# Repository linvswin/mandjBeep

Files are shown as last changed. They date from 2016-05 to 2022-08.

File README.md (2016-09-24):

#### Working in progress !!!
# mandjBeep
## Cosa &egrave;? 
Centralina di allarme modulare pilotata da un atmega1284. 
### Storia
Il progetto &egrave; nato dall'esigenza di in stallare un sistema di allarme in casa. La prima bozza prevedeva l'uso di un atmega328, ma poi con crescere delle
funzionalit&agrave;, sono stato costretto a trovare un microcontrollore con un po di memoria in pi&ugrave;. La scelta &egrave; ricaduta su un atmega1284. Di seguito un comparazione 
tra i microcontrollori pi&ugrave; diffusi (Arduino like) 

<table>
	<tr><th>Feature</th><th>328P</th><th>1284P</th><th>2560P</th></tr>
	<tr><td>Price</td><td>$2.99</td><td>$4.66</td><td>$11.28</td></tr>
	<tr><td>RAM</td><td>2k</td><td>16k</td><td>8k</td></tr>
	<tr><td>Flash</td><td>32k</td><td>128k</td><td>256k</td></tr>
	<tr><td>EEPROM</td><td>1k</td><td>4k</td><td>4k</td></tr>
	<tr><td>UART</td><td>1</td><td>2</td><td>4</td></tr>
	<tr><td>IO Pins</td><td>23</td><td>32</td><td>86</td></tr>
	<tr><td>Interrupts</td><td>2</td><td>3</td><td>8</td></tr>
	<tr><td>Analog Inputs</td><td>6</td><td>8</td><td>16</td></tr>
</table>

### Caratteristiche:

* RTC: modulo DS3231 per la gestione del tempo
* LCD 20x4 per impostazioni/visualizzazione stato, etc (collegato ad un PCF8574 che lo rende I2C)
* tastierino 4x4 (tastierino a membrana classico x arduino collegato ad un PCF8574 che lo rende I2C)
* 2 zone (da implementare)
* avviso tramite modulo GSM (al momento solo tramite sms)
* relay per attivizione sirena.
* batteria tampone al piombo 12v 7A

## Librerie usate

* [Keypad_I2C](https://github.com/joeyoung/arduino_keypads/tree/master/Keypad_I2C): libreria per la gestione del tastierino I2C.
* [LCDMenuLib](https://github.com/Jomelo/LCDMenuLib): libreria per la gestione del menu.
* [secTimer](https://github.com/leomil72/secTimer): Simple seconds counter for Arduino boards and Atmel microcontrollers.
The library can count from 0 to (2^32)-1 seconds. This is a really HUGE
interval of time since (2^32)-1 seconds are about 136 years! So your
device will cease to function before the library will overflow!
* MandjTimer: modificato la libreria [Timer](http://playground.arduino.cc/Code/Timer) per utilizzare secTimer al posto di millis().
* [Password](http://playground.arduino.cc/Code/Password): libreria per la gestione del codice di accesso.
* [PCF8574](https://github.com/RobTillaart/Arduino/tree/master/libraries/PCF8574): libreria per la gestione dei moduli sensore, gestione dell'integrato PCF8574.
* [Rtc_by_Makuna](https://github.com/Makuna/Rtc): liberia per la gestione del modulo DS3231 pe la gestione del tempo.
* [TimerOneThree](https://github.com/heliosoph/TimerOneThree):  The arduino TimerOne library adapted for ATmega1284P and extended for timer3.
* [GSM Shield](http://www.gsmlib.org): a library developed for Arduino's shields that support SIM900/SIM908.
* [Keypad](http://playground.arduino.cc/Code/Keypad): a library for using <em>matrix</em> style keypads with the Arduino. As of version 3.0 it now supports mulitple keypresses.
* [NewLiquidCrystal](https://bitbucket.org/fmalpartida/new-liquidcrystal/wiki/Home): the <em>LCD Library</em> for <strong>Arduino</strong> and <strong>Chipkit</strong>. It is a derivate of the original LiquidCrystal Library as sourced in the Arduino SDK. It has been developed to be compatible with the current LiquidCrystal library, its performance is almost 5 times faster and fully extendable if need be.
* [SoftwareSerial](https://www.arduino.cc/en/Reference/SoftwareSerial): library has been developed to allow serial communication on other digital pins of the Arduino, using software to replicate the functionality.
* [Wire](https://www.arduino.cc/en/Reference/Wire): library allows you to communicate with <span class="wikiword">I2C</span> / TWI devices.
 
##  Author

* M&J 
* Sito: [siatienfalla](http://siatienfalla.altervista.org/)
* Data inizio: 09/02/2016
* Versione: 1.0
 
## Licence: GPL ver. 3

## Immagini
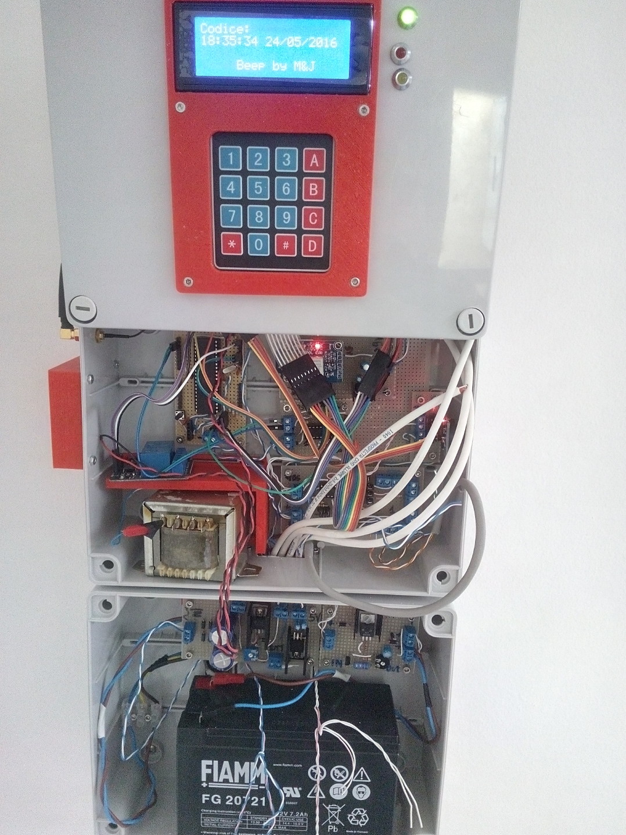
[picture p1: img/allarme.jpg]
Allarme


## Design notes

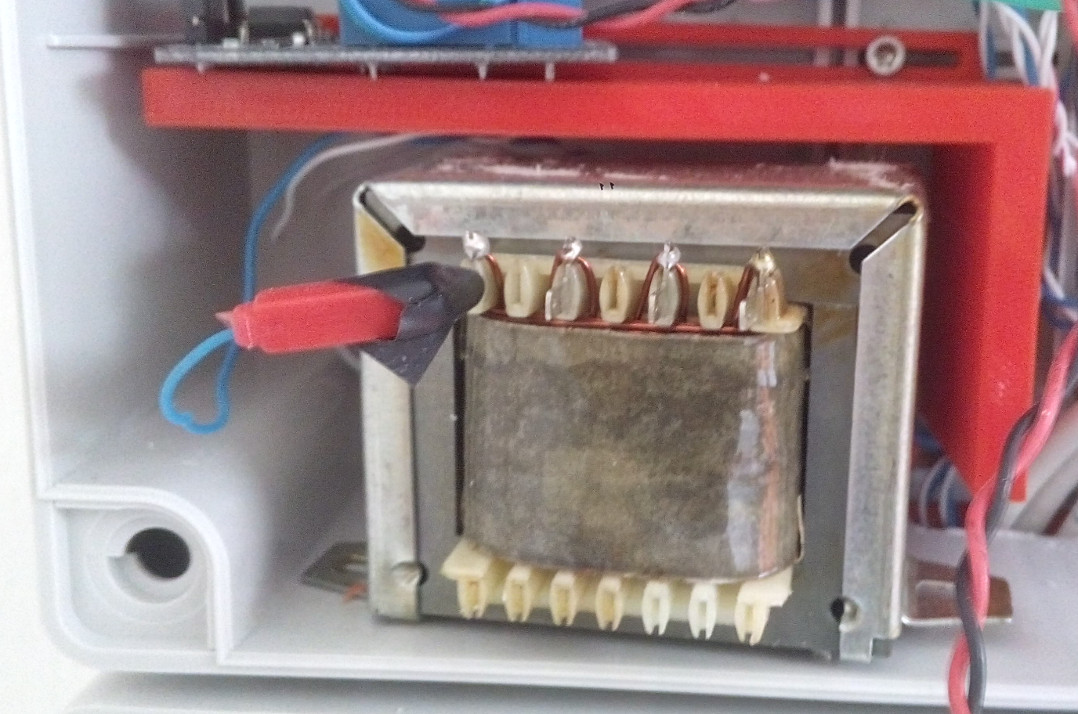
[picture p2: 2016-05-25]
img/moduloTrasformatore.jpg

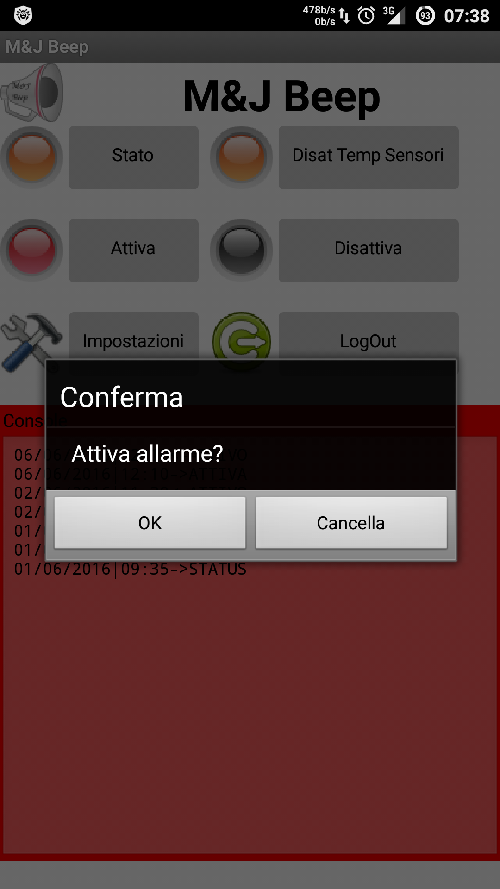
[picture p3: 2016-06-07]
android/img/Screenshot_2016-06-06-07-38-11.png

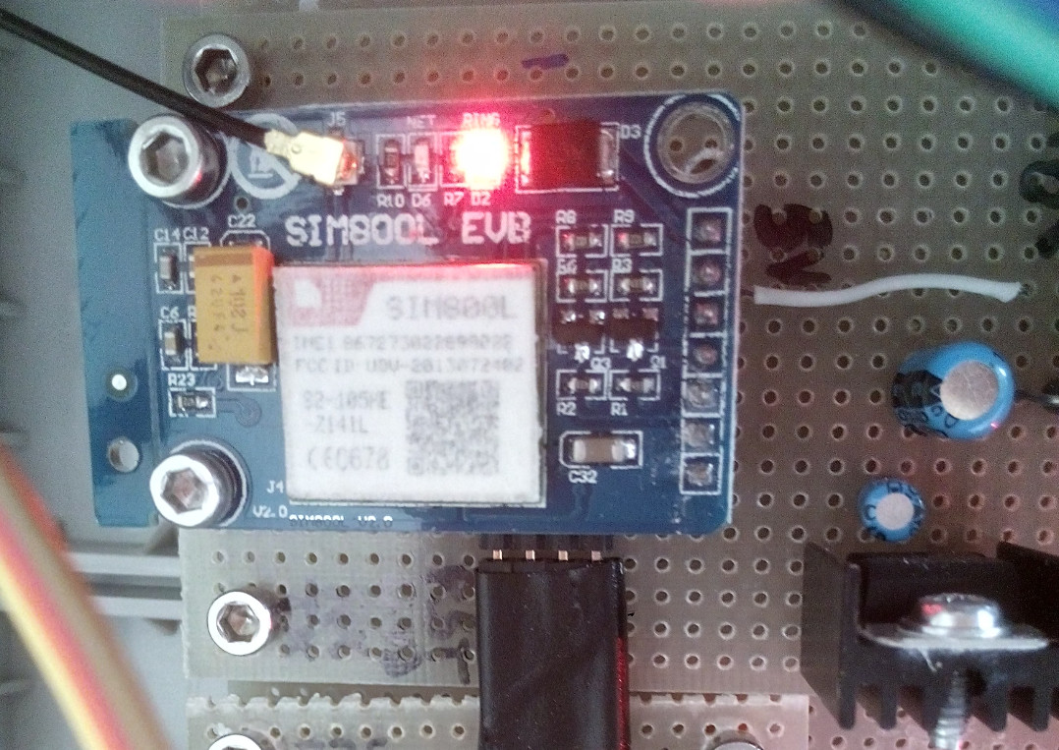
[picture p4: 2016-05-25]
img/moduloGSM.jpg

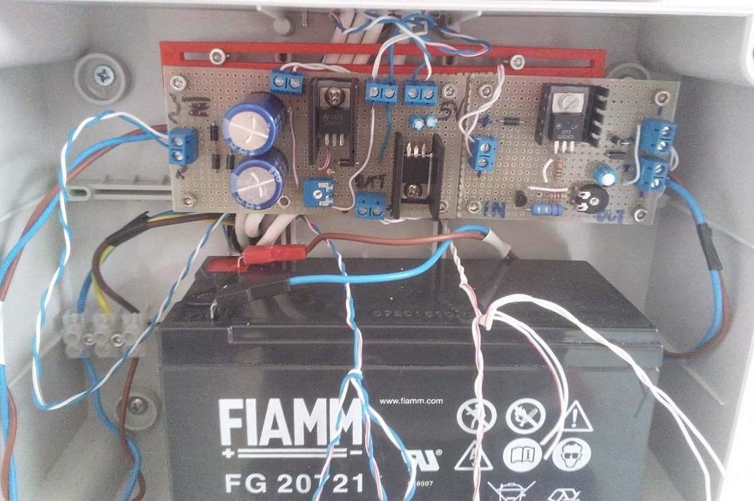
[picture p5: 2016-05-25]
img/moduloAlimentazione.jpg

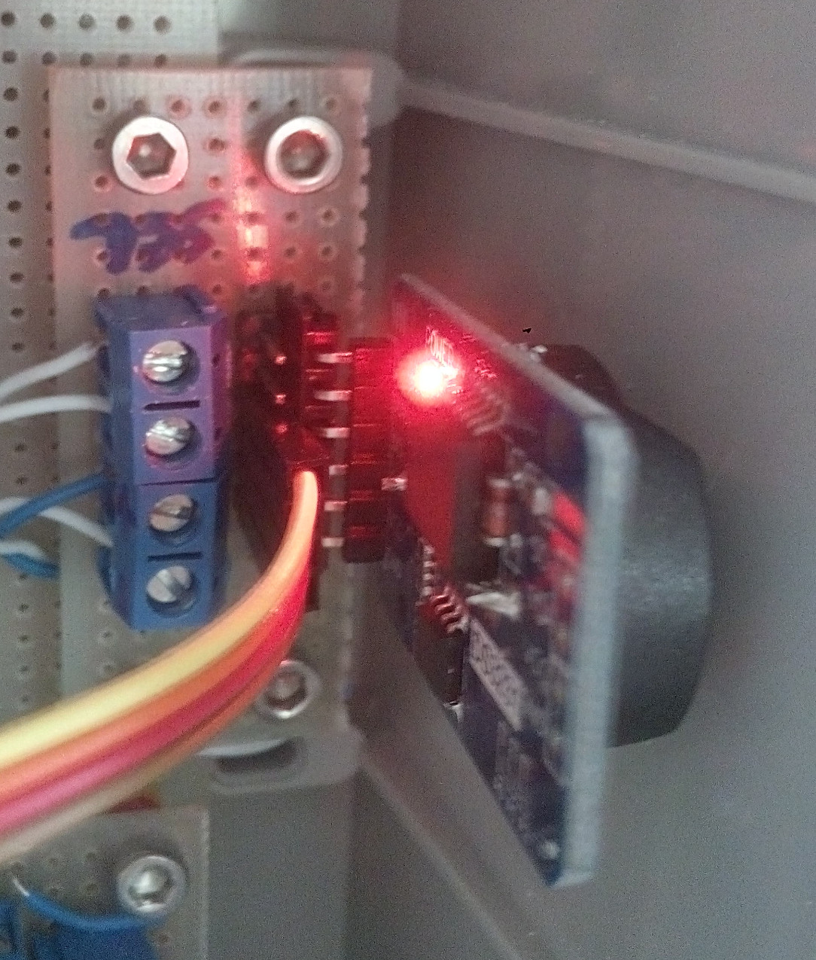
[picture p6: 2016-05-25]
img/moduloTempoLCD.jpg

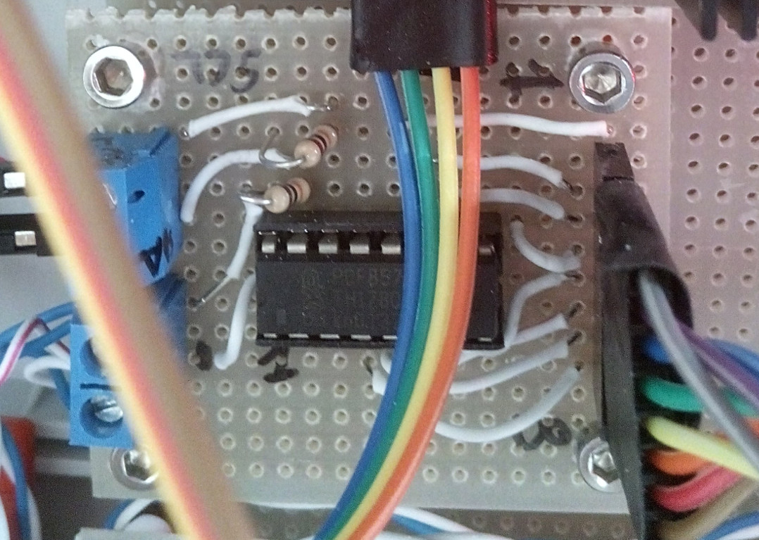
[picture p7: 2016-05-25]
img/moduloKeyPad.jpg

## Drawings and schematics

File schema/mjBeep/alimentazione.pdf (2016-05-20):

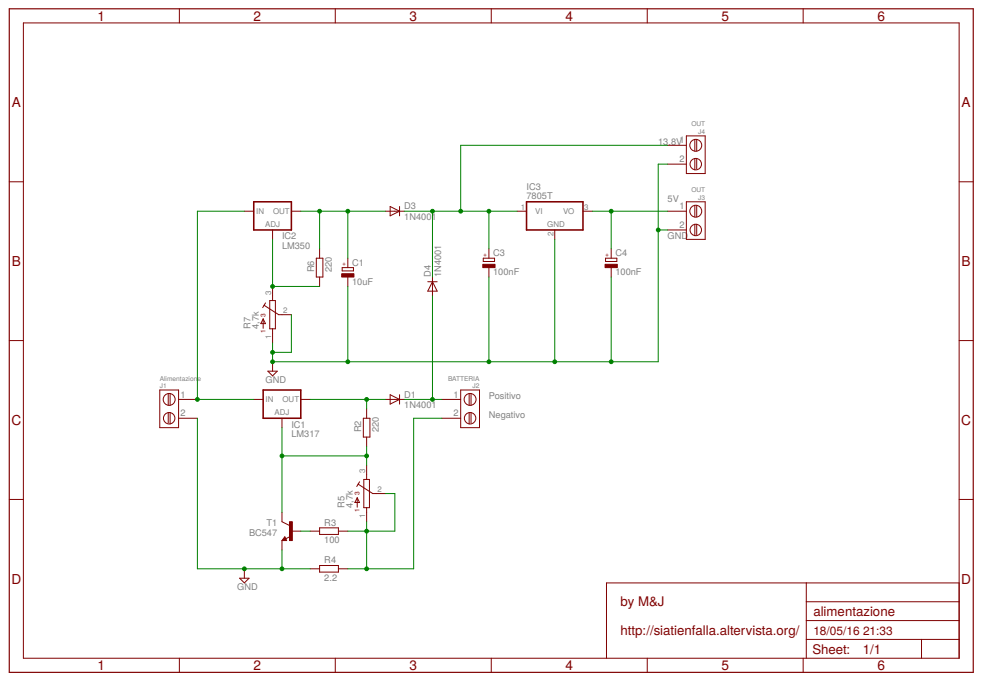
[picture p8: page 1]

by M&J http://siatienfalla.altervista.org/

Sheet: 1/1

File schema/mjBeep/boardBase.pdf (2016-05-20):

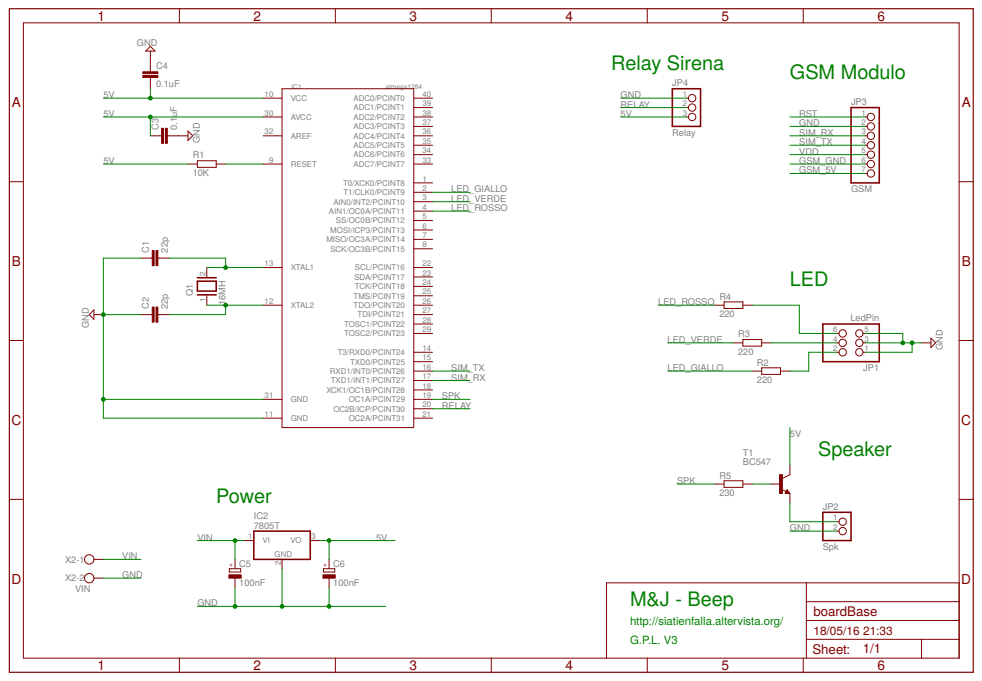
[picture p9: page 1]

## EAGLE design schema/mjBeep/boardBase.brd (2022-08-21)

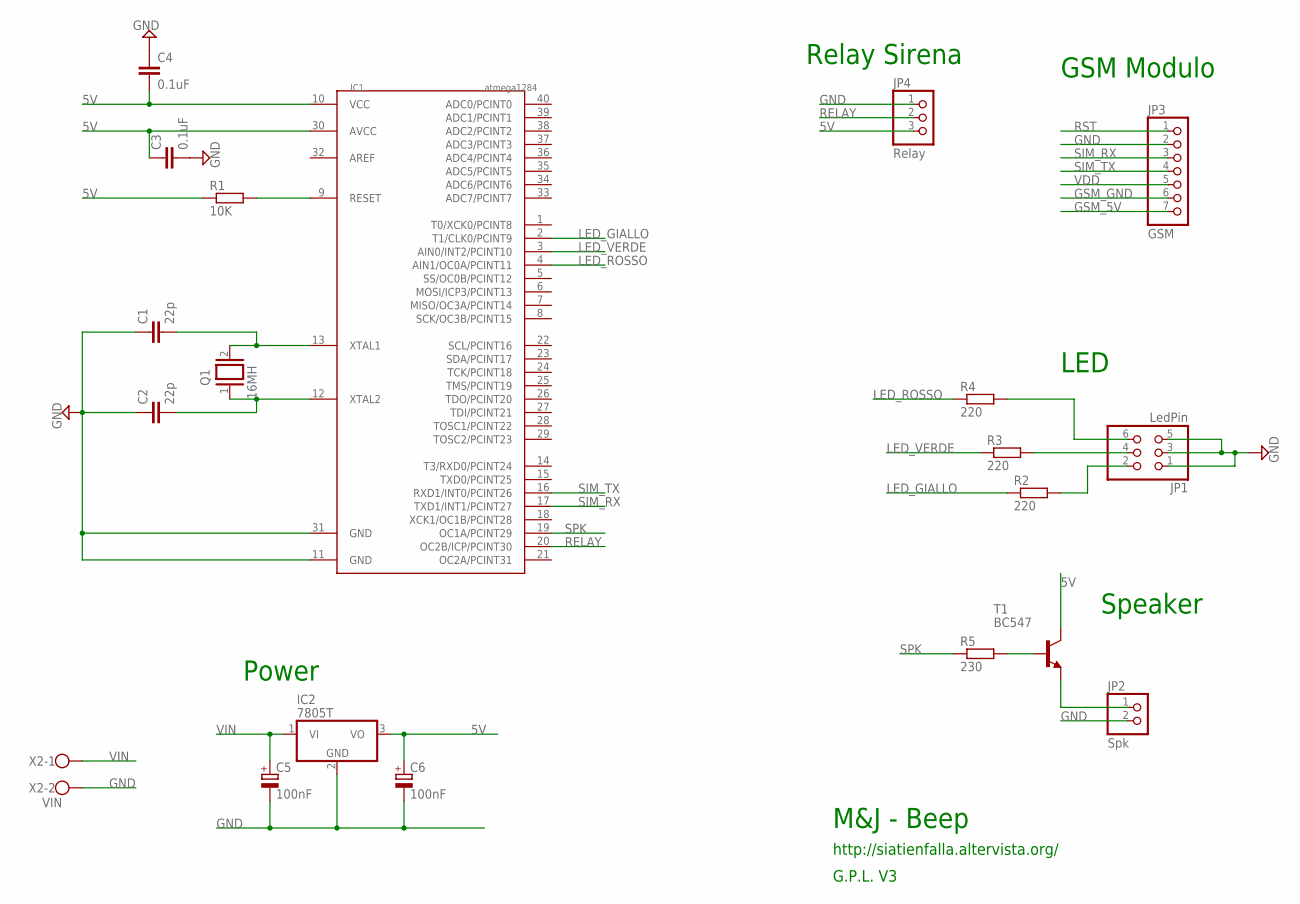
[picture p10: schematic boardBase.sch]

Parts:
C1, C2: 22p; C025-024X044
C3, C4: 0.1uF; C025-025X050
C5, C6: 100nF; E3,5-10
IC1: atmega1284; DIL40
IC2: 7805T; TO220H
JP1: LedPin; 2X03
JP2: Spk; 1X02
JP3: GSM; 1X07
JP4: Relay; 1X03
Q1: 16MH; QS
R1: 10K; 0207/10
R2, R3, R4: 220; 0207/10
R5: 230; 0207/10
T1: BC547; TO92
X2: VIN; W237-102

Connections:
5V: C3.1, C4.2, C6.+, IC1.10 (VCC), IC1.30 (AVCC), IC2.3 (VO), JP4.3, R1.1, T1.3 (C)
GND: C1.1, C2.1, C3.2, C4.1, C5.-, C6.-, IC1.11 (GND), IC1.31 (GND), IC2.2 (GND), JP1.1, JP1.3, JP1.5, JP2.2, JP3.2, JP4.1, X2.2
GSM_5V: JP3.7
GSM_GND: JP3.6
LED_GIALLO: IC1.2 (T1/CLK0/PCINT9), R2.1
LED_ROSSO: IC1.4 (AIN1/OC0A/PCINT11), R4.1
LED_VERDE: IC1.3 (AIN0/INT2/PCINT10), R3.1
unnamed: C2.2, IC1.12 (XTAL2), Q1.1
unnamed: C1.2, IC1.13 (XTAL1), Q1.2
unnamed: IC1.9 (RESET), R1.2
unnamed: JP1.2, R2.2
unnamed: JP1.4, R3.2
unnamed: JP1.6, R4.2
unnamed: R5.2, T1.2 (B)
unnamed: JP2.1, T1.1 (E)
RELAY: IC1.20 (OC2B/ICP/PCINT30), JP4.2
RST: JP3.1
SIM_RX: IC1.17 (TXD1/INT1/PCINT27), JP3.3
SIM_TX: IC1.16 (RXD1/INT0/PCINT26), JP3.4
SPK: IC1.19 (OC1A/PCINT29), R5.1
VDD: JP3.5
VIN: C5.+, IC2.1 (VI), X2.1

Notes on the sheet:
Speaker
Relay Sirena
LED
Power
GSM Modulo
M&J - Beep
http://siatienfalla.altervista.org/
G.P.L. V3

Board: 2 copper layers, 20 parts (0 on the bottom side), 18 nets, no tracks yet.

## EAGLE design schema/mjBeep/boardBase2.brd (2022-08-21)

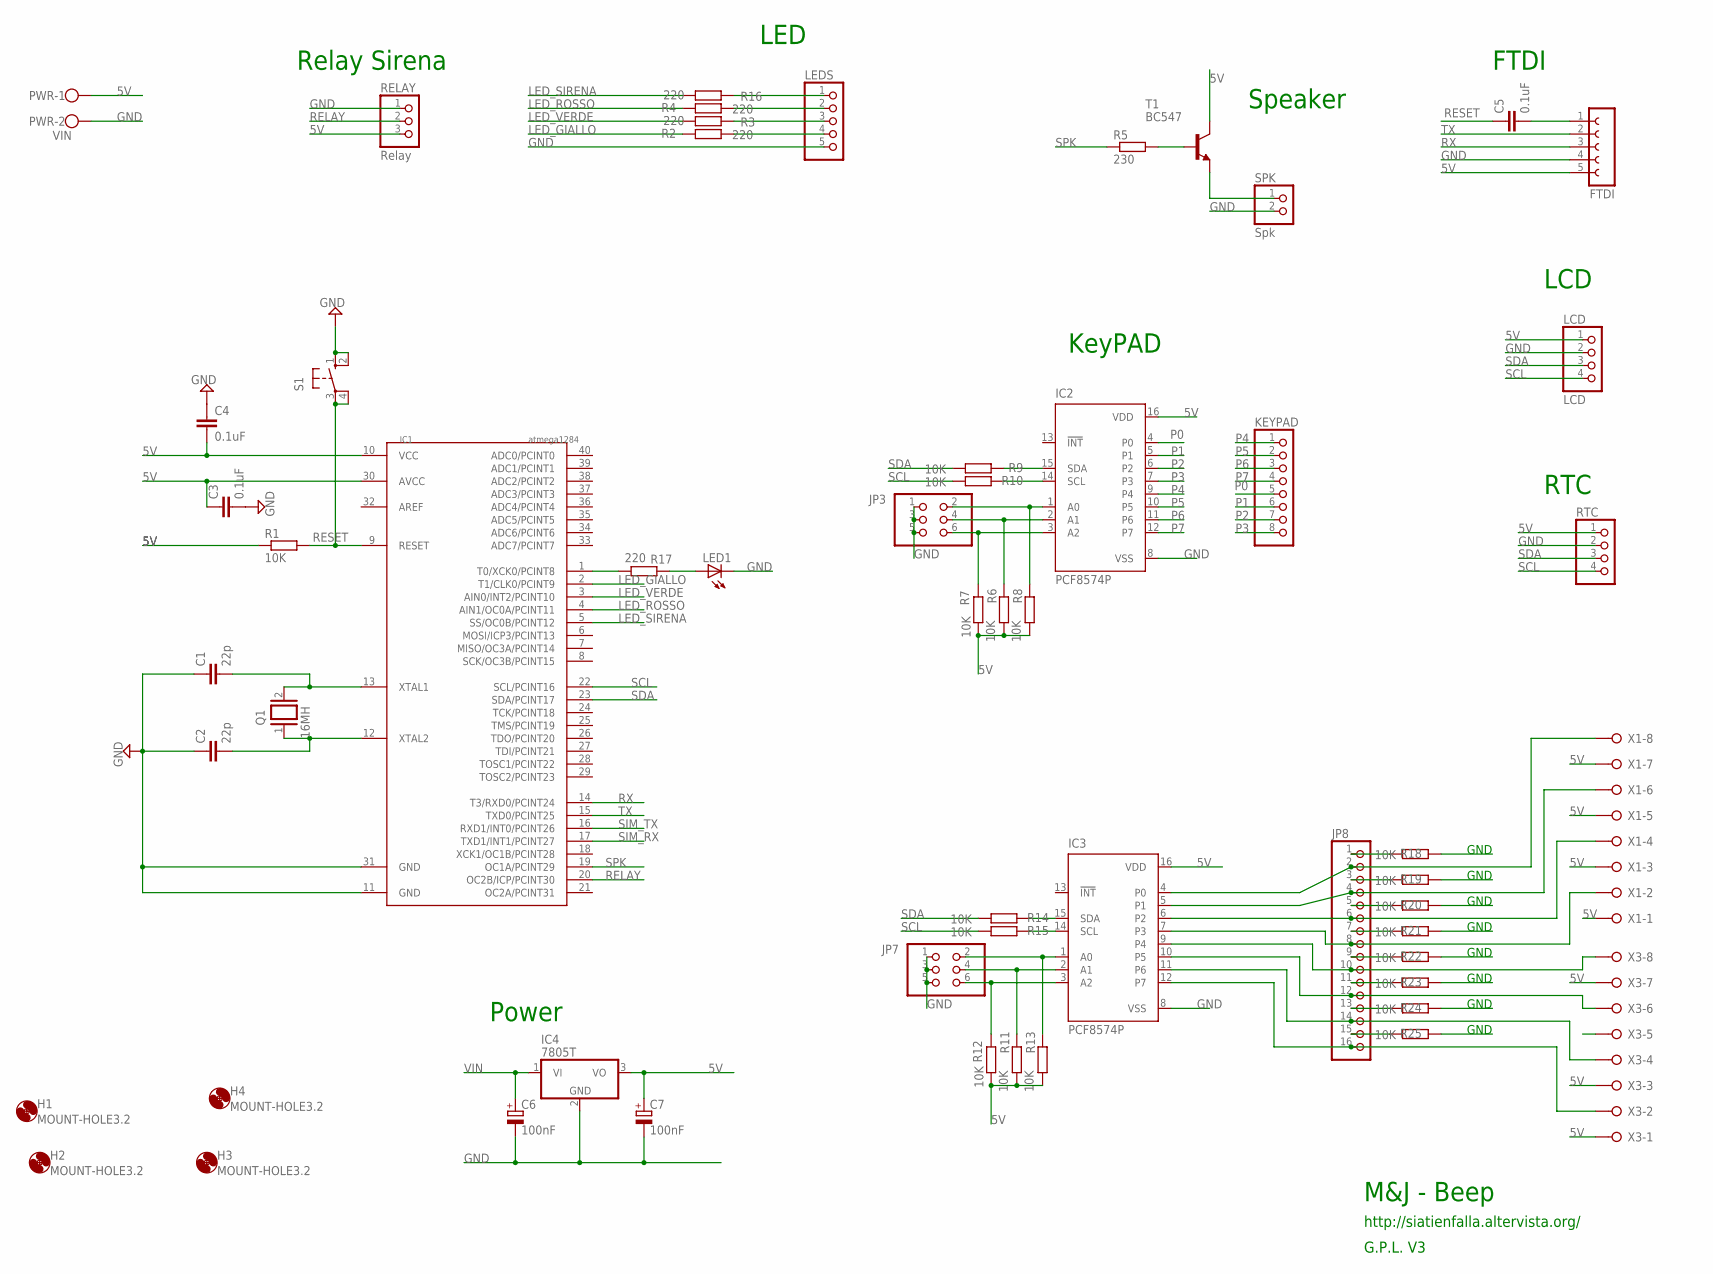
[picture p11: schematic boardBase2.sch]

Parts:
C1, C2: 22p; C025-024X044
C3, C4, C5: 0.1uF; C025-025X050
C6, C7: 100nF; E3,5-10
FTDI: FE05-1
H1, H2, H3, H4: MOUNT-HOLE3.2; 3,2
IC1: atmega1284; DIL40
IC2, IC3: PCF8574P; DIL16
IC4: 7805T; TO220H
JP3, JP7: PINHD-2X3; 2X03
JP8: PINHD-1X16; 1X16
KEYPAD: PINHD-1X8; 1X08
LCD: LCD; 1X04
LED1: LED3MM
LEDS: PINHD-1X5; 1X05
PWR: VIN; W237-102
Q1: 16MH; QS
R1, R6, R7, R8, R9, R10: 10K; 0207/10
R2, R3, R4, R16, R17: 220; 0207/2V
R5: 230; 0207/10
R11, R12, R13, R14, R15, R18, R19, R20, R21, R22, R23, R24, R25: 10K; 0207/2V
RELAY: Relay; 1X03
RTC: PINHD-1X4; 1X04
S1: 10-XX; B3F-10XX
SPK: Spk; 1X02
T1: BC547; TO92
X1, X3: W237-08P; W237-8P

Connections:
5V: C3.1, C4.2, C7.+, FTDI.5, IC1.10 (VCC), IC1.30 (AVCC), IC2.16 (VDD), IC3.16 (VDD), IC4.3 (VO), LCD.1, PWR.1, R1.1, R6.1, R7.2, R8.1, R11.1, R12.2, R13.1, RELAY.3, RTC.1, T1.3 (C), X1.1, X1.3, X1.5, X1.7, X3.1, X3.3, X3.5, X3.7
GND: C1.1, C2.1, C3.2, C4.1, C6.-, C7.-, FTDI.4, IC1.11 (GND), IC1.31 (GND), IC2.8 (VSS), IC3.8 (VSS), IC4.2 (GND), JP3.1, JP3.3, JP3.5, JP7.1, JP7.3, JP7.5, LCD.2, LED1.K (C), LEDS.5, PWR.2, R18.1, R19.1, R21.1, R22.1, R23.1, R24.1, R25.1, RELAY.1, RTC.2, S1.1 (S), S1.2 (S1), SPK.2
LED_GIALLO: IC1.2 (T1/CLK0/PCINT9), R2.2
LED_ROSSO: IC1.4 (AIN1/OC0A/PCINT11), R4.2
LED_SIRENA: IC1.5 (SS/OC0B/PCINT12), R16.1
LED_VERDE: IC1.3 (AIN0/INT2/PCINT10), R3.1
unnamed: C2.2, IC1.12 (XTAL2), Q1.1
unnamed: C1.2, IC1.13 (XTAL1), Q1.2
unnamed: IC2.1 (A0), JP3.2, R8.2
unnamed: C5.2, FTDI.1
unnamed: IC2.2 (A1), JP3.4, R6.2
unnamed: IC2.3 (A2), JP3.6, R7.1
unnamed: LEDS.4, R2.1
unnamed: LEDS.3, R3.2
unnamed: LEDS.2, R4.1
unnamed: IC2.14 (SCL), R10.1
unnamed: R5.2, T1.2 (B)
unnamed: SPK.1, T1.1 (E)
unnamed: IC2.15 (SDA), R9.1
unnamed: IC3.1 (A0), JP7.2, R13.2
unnamed: IC3.2 (A1), JP7.4, R11.2
unnamed: IC3.3 (A2), JP7.6, R12.1
unnamed: IC3.14 (SCL), R15.1
unnamed: IC3.15 (SDA), R14.1
unnamed: LEDS.1, R16.2
unnamed: IC1.1 (T0/XCK0/PCINT8), R17.1
unnamed: LED1.A, R17.2
unnamed: IC3.4 (P0), JP8.2, X1.8
unnamed: IC3.5 (P1), JP8.4, X1.6
unnamed: IC3.6 (P2), JP8.6, X1.4
unnamed: IC3.7 (P3), JP8.8, X1.2
unnamed: IC3.9 (P4), JP8.10, X3.8
unnamed: IC3.10 (P5), JP8.12, X3.6
unnamed: IC3.11 (P6), JP8.14, X3.4
unnamed: IC3.12 (P7), JP8.16, X3.2
unnamed: JP8.1, R18.2
unnamed: JP8.3, R19.2
unnamed: JP8.5, R20.2
unnamed: JP8.7, R21.2
unnamed: JP8.9, R22.2
unnamed: JP8.11, R23.2
unnamed: JP8.13, R24.2
unnamed: JP8.15, R25.2
P0: IC2.4 (P0), KEYPAD.5
P1: IC2.5 (P1), KEYPAD.6
P2: IC2.6 (P2), KEYPAD.7
P3: IC2.7 (P3), KEYPAD.8
P4: IC2.9 (P4), KEYPAD.1
P5: IC2.10 (P5), KEYPAD.2
P6: IC2.11 (P6), KEYPAD.3
P7: IC2.12 (P7), KEYPAD.4
RELAY: IC1.20 (OC2B/ICP/PCINT30), RELAY.2
RESET: C5.1, IC1.9 (RESET), R1.2, S1.3, S1.4 (P1)
RX: FTDI.3, IC1.14 (T3/RXD0/PCINT24)
SCL: IC1.22 (SCL/PCINT16), LCD.4, R10.2, R15.2, RTC.4
SDA: IC1.23 (SDA/PCINT17), LCD.3, R9.2, R14.2, RTC.3
SIM_RX: IC1.17 (TXD1/INT1/PCINT27)
SIM_TX: IC1.16 (RXD1/INT0/PCINT26)
SPK: IC1.19 (OC1A/PCINT29), R5.1
TX: FTDI.2, IC1.15 (TXD0/PCINT25)
VIN: C6.+, IC4.1 (VI)

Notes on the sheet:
Speaker
Relay Sirena
LED
M&J - Beep
http://siatienfalla.altervista.org/
G.P.L. V3
FTDI
KeyPAD
GND
RTC
LCD
Power

Board: 2 copper layers, 57 parts (1 on the bottom side), 59 nets, no tracks yet.

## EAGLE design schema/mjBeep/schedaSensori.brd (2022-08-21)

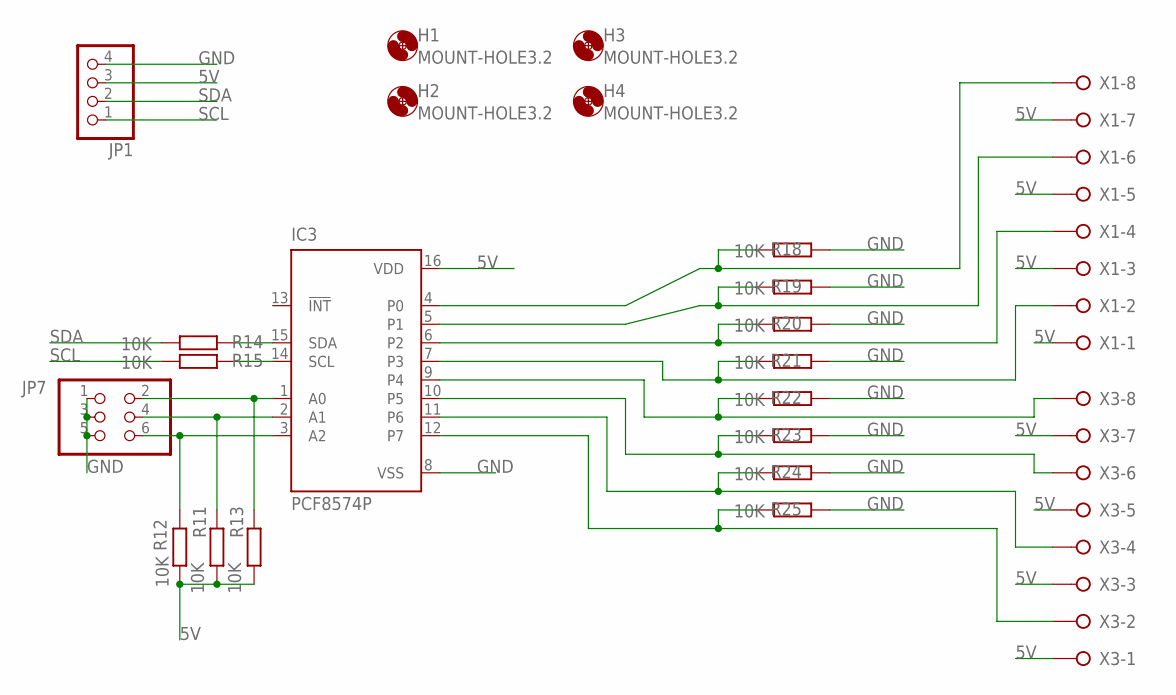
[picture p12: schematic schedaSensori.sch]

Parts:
H1, H2, H3, H4: MOUNT-HOLE3.2; 3,2
IC3: PCF8574P; DIL16
JP1: PINHD-1X4; 1X04
JP7: PINHD-2X3; 2X03
R11, R12, R13, R14, R15, R18, R19, R20, R21, R22, R23, R24, R25: 10K; 0207/10
X1, X3: W237-08P; W237-8P

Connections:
5V: IC3.16 (VDD), JP1.3, R11.1, R12.2, R13.1, X1.1, X1.3, X1.5, X1.7, X3.1, X3.3, X3.5, X3.7
GND: IC3.8 (VSS), JP1.4, JP7.1, JP7.3, JP7.5, R18.1, R19.1, R20.1, R21.1, R22.1, R23.1, R24.1, R25.1
unnamed: IC3.1 (A0), JP7.2, R13.2
unnamed: IC3.2 (A1), JP7.4, R11.2
unnamed: IC3.3 (A2), JP7.6, R12.1
unnamed: IC3.14 (SCL), R15.1
unnamed: IC3.15 (SDA), R14.1
unnamed: IC3.4 (P0), R18.2, X1.8
unnamed: IC3.5 (P1), R19.2, X1.6
unnamed: IC3.6 (P2), R20.2, X1.4
unnamed: IC3.7 (P3), R21.2, X1.2
unnamed: IC3.9 (P4), R22.2, X3.8
unnamed: IC3.10 (P5), R23.2, X3.6
unnamed: IC3.11 (P6), R24.2, X3.4
unnamed: IC3.12 (P7), R25.2, X3.2
SCL: JP1.1, R15.2
SDA: JP1.2, R14.2

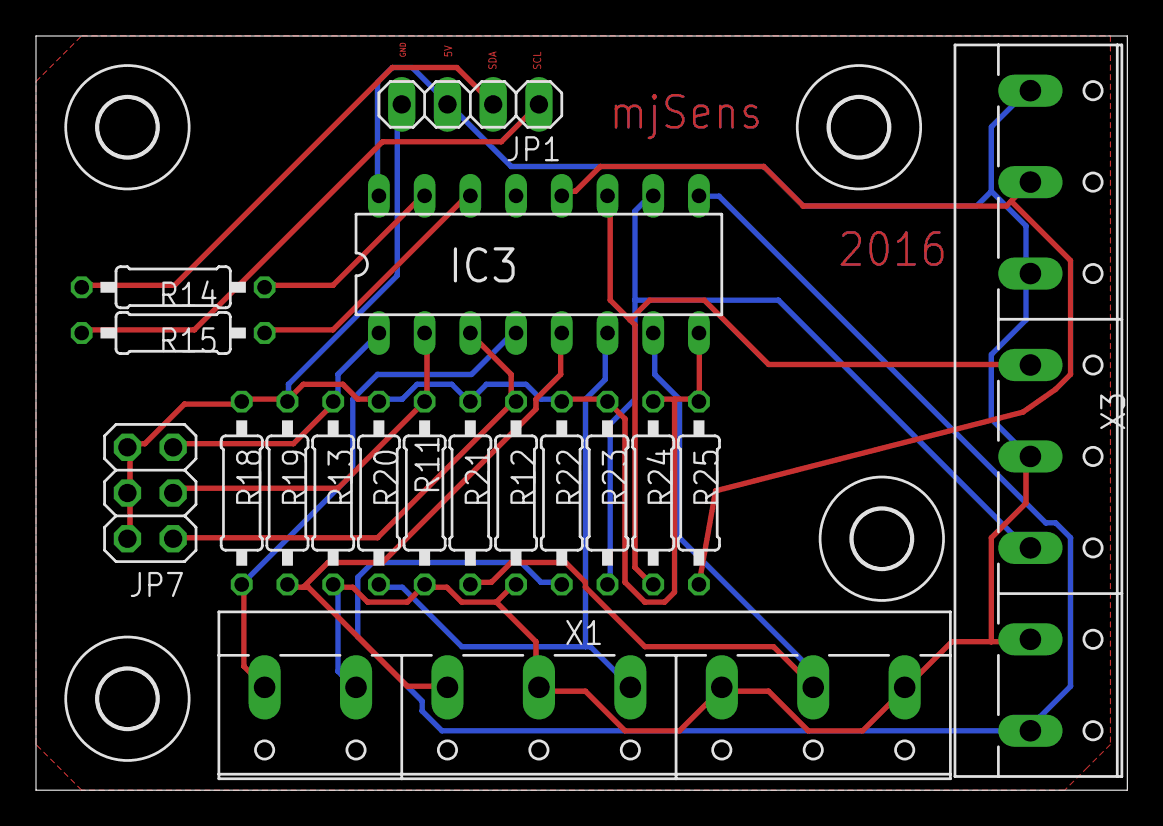
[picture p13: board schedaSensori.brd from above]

Board: 2 copper layers, 60.6 x 41.9 mm, 22 parts (0 on the bottom side), 17 nets.

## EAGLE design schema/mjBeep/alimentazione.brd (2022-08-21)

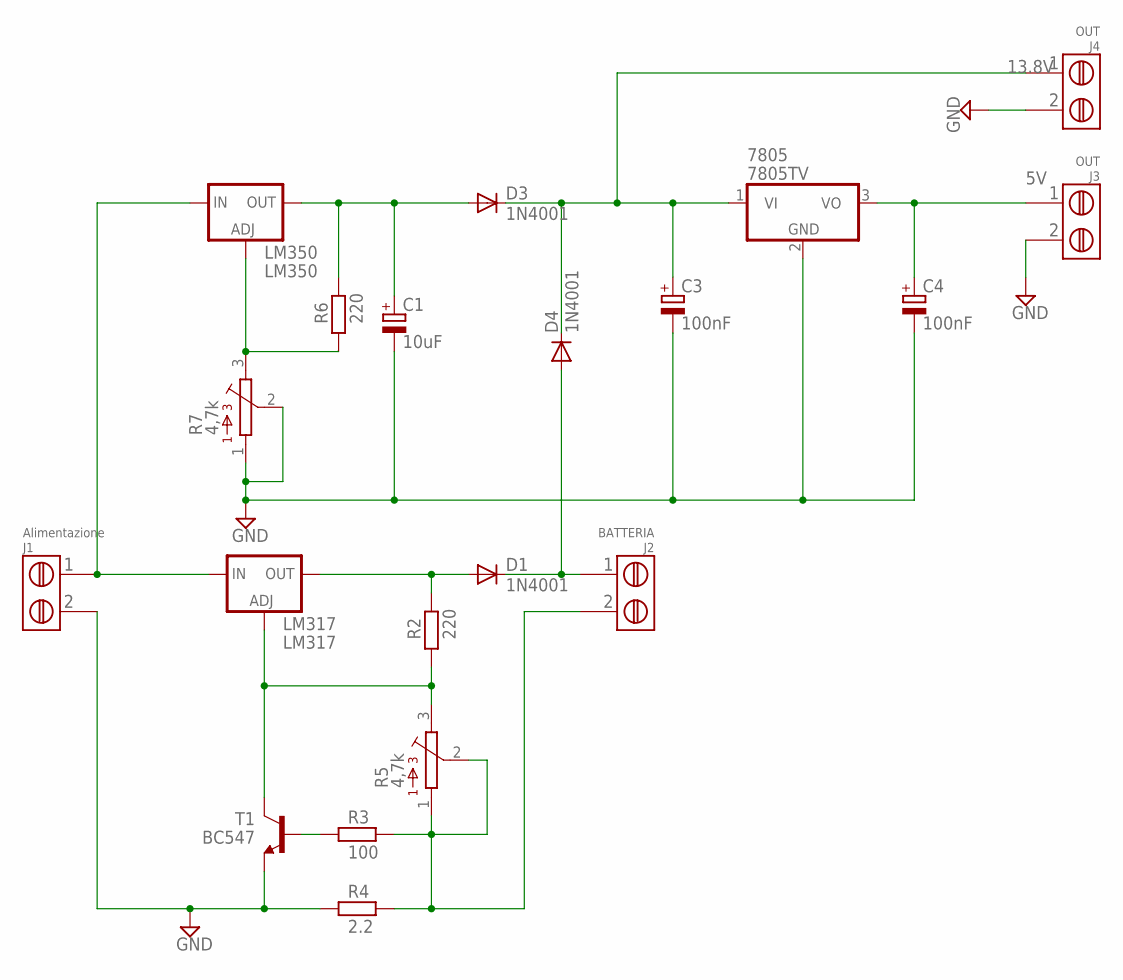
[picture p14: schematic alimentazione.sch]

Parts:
7805: 7805TV; TO220V
C1: 10uF; E2,5-6
C3, C4: 100nF; E2,5-6
D1, D3, D4: 1N4001; DO41-10
J1: Alimentazione; MORSETTIERA
J2: BATTERIA; MORSETTIERA
J3, J4: OUT; MORSETTIERA
LM317: LM317; 317TS
LM350: LM350; 317TS
R2, R6: 220; R1/4W
R3: 100; R1/4W
R4: 2.2; R1/4W
R5, R7: 4,7k; CA9V
T1: BC547; TO92

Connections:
5V: 7805.3 (VO), C4.+, J3.1
13.8V: 7805.1 (VI), C3.+, D3.C (K), D4.C (K), J4.1
+BAT: D1.C (K), D4.A, J2.1
-BAT: J2.2, R3.2, R4.2, R5.1, R5.2
GND: 7805.2 (GND), C1.-, C3.-, C4.-, J1.2, J3.2, J4.2, R4.1, R7.1, R7.2, T1.1 (E)
unnamed: C1.+, D3.A, LM350.2 (OUT), R6.2
unnamed: R3.1, T1.2 (B)
unnamed: LM350.1 (ADJ), R6.1, R7.3
unnamed: J1.1, LM317.3 (IN), LM350.3 (IN)
unnamed: D1.A, LM317.2 (OUT), R2.2
unnamed: LM317.1 (ADJ), R2.1, R5.3, T1.3 (C)

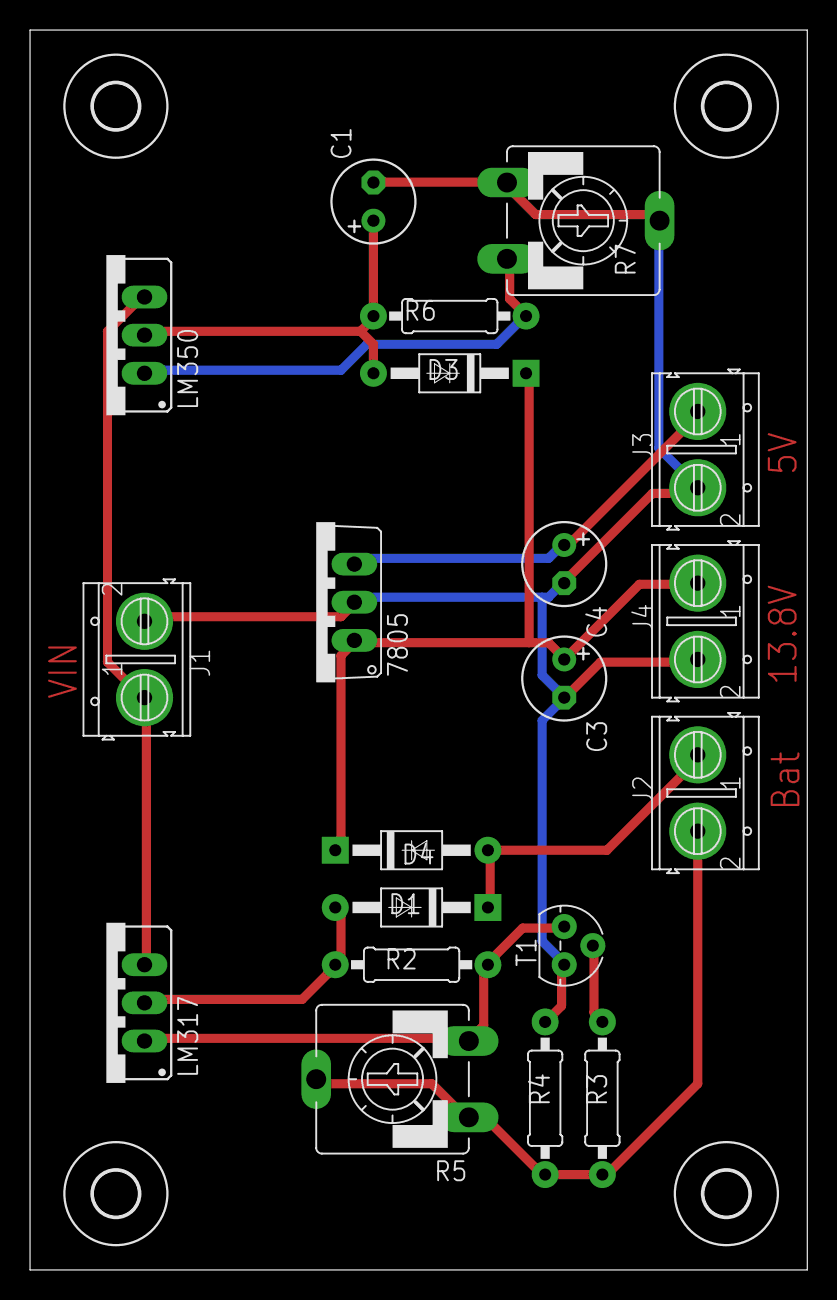
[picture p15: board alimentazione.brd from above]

Board: 2 copper layers, 51.7 x 82.5 mm, 24 parts (0 on the bottom side), 11 nets.

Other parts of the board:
U$1, U$2, U$3, U$4: 3,0

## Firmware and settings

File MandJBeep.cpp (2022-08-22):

/**
 * Project Title: M&J Beep
 * Author: M&J
 * Started Date: 09/02/2016
 * Version: 1.0
 * Licence: GPL ver 3
 * Note: basato sul progetto Home Security System di Jun Peng - Tech 169
 **/

#include "MandJBeep.h"

String outputString = "";
boolean stringComplete = false;

String printDigit(int digits) {
  String temp = "";
  if (digits < 10)
    temp += "0";
  temp += digits;
  return temp;
}

void setup() {
  Serial.begin(BAUD_RATE);
  Wire.begin();  // join i2c bus (address optional for master)

  allarm.inizializza();
  allarm.setPassword(settings.alarmPassword1);

  allarm.lcd.begin(20, 4);
  MenuSetup();

#ifdef DEBUG_SETTINGS
  Serial.print(F("Setting sizeof: "));
  Serial.println(sizeof(settings));
  printSettings();
#endif

  allarm.standby();

  allarm.mjTimer.startTimer();
  // avvia evento stampa data ogni secondo
  timerPrintData = allarm.mjTimer.every(1, printDate);
  // attiva evento spegni LCD dopo lcdBacklightTime secondi
  timerLCDbacklight = allarm.mjTimer.every(settings.lcdBacklightTime,
                                           timerDoLCDbacklight);
  //
  timerReadGSMSlave = allarm.mjTimer.every(1, readGSMSlave);

  /*if (settings.gsm == 1) {
	 lcd.setCursor(0, 2);
	 lcd.println(TXT_INIZIALIZZA_GSM);
	 //allarm.inizializzaGSM();
	 allarm.standby();
	 }*/

  // attivo watchdog 8s
  wdt_enable(WDTO_8S);
}

void loop() {

#ifndef CLKDS3231
  allarm.now = allarm.clock.RTC.now();
#else
  allarm.clock.now = allarm.clock.RTC.GetDateTime();
#endif

  keypad.getKey();
  allarm.checkSMS();       // legge la presenza di messaggi sms
  allarm.checkAttivita();  // legge lo stato dei sensori

  MenuLoop();
  allarm.mjTimer.update();

  // reset il  watchdog
  wdt_reset();
}

void keypadEvent(KeypadEvent eKey) {

#ifdef DEBUG
#ifdef DEBUG_KEY
  Serial.print(F("Tasto: "));
  Serial.println(eKey);
  lcd.setCursor(0, 2);
  lcd.print(eKey);
#endif
#endif

  switch (keypad.getState()) {
    case PRESSED:
      if (passwd_pos - 9 >= 10) {
        //return;
        passwd_pos = 9;
      }
      allarm.lcd.backlight();
      allarm.mjTimer.stop(timerLCDbacklight);
      timerLCDbacklight = allarm.mjTimer.every(settings.lcdBacklightTime,
                                               timerDoLCDbacklight);

      switch (eKey) {
        case '#':
          if (mostraMenu == false) {  //# is to validate password
            passwd_pos = 9;
            allarm.checkPassword();
          } else {
            LCDML_BUTTON_enter();
          }
          break;
        case '*':  //* is to reset password attempt
          if (mostraMenu == false) {
            allarm.password.reset();
            passwd_pos = 9;
            mostraMenu = false;
            allarm.standby();
          } else {
            LCDML_BUTTON_quit();
          }
          break;
        case 'A':
          if (mostraMenu == false) {
            if (allarm.statoAllarme == false) {
              allarm.primaDiAttivare();
              //	disattivaSensori();
            }
          }
          break;
        case 'B':
          if (mostraMenu == false) {
            passwd_pos = 9;
            allarm.password.set(settings.menuPassword);
            if (allarm.checkPassword2()) {
              allarm.mjTimer.stop(timerPrintData);
              mostraMenu = true;
              LCDML.goRoot();
              LCDML_BUTTON_up();
            } else
              allarm.codiceErrato(1);
          } else {
            allarm.password.reset();
            allarm.password.set(settings.alarmPassword1);
            mostraMenu = false;
            timerPrintData = allarm.mjTimer.every(1, printDate);
            allarm.standby();
          }
          break;
        case 'C':
          if (mostraMenu == false) {
            allarm.lcd.backlight();
          } else {
            LCDML_BUTTON_up();
          }
          break;
        case 'D':
          if (mostraMenu == false) {
            //lcd.noBacklight();
          } else {
            LCDML_BUTTON_down();
          }
          break;
        default:
          if (mostraMenu == false) {
            allarm.password.append(eKey);
            allarm.lcd.setCursor((passwd_pos++), 0);
            allarm.lcd.print(F("*"));
          } else {
            if (mnuNewTxtVal == 0) {
              if (indNewTxtVal < PasswordLength_Max - 1) {
                newTxtVal[indNewTxtVal] = eKey;
                indNewTxtVal++;
              }
            } else if (mnuNewTxtVal == 1) {
              if (indNewTxtVal2 < 19) {
                newTxtVal2[indNewTxtVal2] = eKey;
                indNewTxtVal2++;
              }
            }
          }
          break;
      }
  }
}

void printDate() {
  //TIME and DATE
  allarm.lcd.setCursor(0, 1);
  allarm.lcd.print(allarm.clock.getDate());
}

#ifdef DEBUG_SETTINGS
void printSettings() {
  Serial.print(F("tempo sirena: "));
  Serial.println(settings.tempoSirena);
  Serial.print(F("tempo lcd: "));
  Serial.println(settings.lcdBacklightTime);
  Serial.print(F("conta REED: "));
  Serial.println(settings.maxReed_Conta);
  Serial.print(F("sens: "));
  Serial.println(settings.sens);
  Serial.print(F("zona: "));
  Serial.println(settings.zona);
  Serial.print(F("AdminPassword: "));
  Serial.println(settings.menuPassword);
  Serial.print(F("Password1: "));
  Serial.println(settings.alarmPassword1);
  Serial.print(F("Password2: "));
  Serial.println(settings.alarmPassword2);
}
#endif

/**
 * evento che si ripete ogni 5s. Interroga lo slaveGSM per valutarne lo stato
 **/
void readGSMSlave() {
  //*if (stringComplete == true) {
  Wire.requestFrom(GSMI2C, 1);  // request 6 bytes from slave device #8
  while (Wire.available()) {    // slave may send less than requested
    //byte c = Wire.read(); // receive a byte as character
    risposteGSMSlave = Wire.read();  // receive a byte as character
                                     //Serial.println(c);         // print the character
  }
  //}*/
}

/*
 * evento dopo ritardo attivazione
 */
void doAfterRitActivate() {
#ifdef DEBUG
  Serial.println(F("Attivo Allarme"));
#endif
  conta = 0;
  //allarm.attiva();
  allarm.ritardoAttivato = false;
  mostraMenu = false;
  allarm.standby();
}

/*
 * evento dopo tempoSirena:
 *   - disattiva Timer1PWM
 *   - disattiva sirena
 *   - cambia stato al sensore attivato
 */
void doAfterTimerT() {
  Timer1.disablePwm(TIMER1_PIN1);

  digitalWrite(RELAY_SIRENA1, HIGH);
  for (int i = 0; i < numSens; i++) {
    if (sensore[i].getStato() == sensTrigged)
      sensore[i].setStato(sensAttivo);
  }
}

bool setPulseWidth(long microseconds) {
  //bool ret = false;
  //int prescaleValue = prescale[Timer1.clockSelectBits];

  // calculate time per counter tick in nanoseconds
  long precision = (F_CPU / 128000) * prescale[Timer1.clockSelectBits];
  period = precision * ICR1 / 1000;  // period in microseconds
  if (microseconds < period) {
    int duty = map(microseconds, 0, period, 0, 1024);
    if (duty < 1)
      duty = 1;
    if (microseconds > 0 && duty < RESOLUTION) {
      Timer1.pwm(TIMER1_PIN1, duty);
      return true;
    }
  }
  return false;
}

int xxxx = 0;

void doPrintRitAttivazione() {
  //standby();
  allarm.lcd.setCursor(0, 2);
  allarm.lcd.print(F("Rit. "));
  allarm.lcd.print(++conta);

  if (xxxx == 0) {
    xxxx = 1;
    Timer1.initialize(period);  // initialize timer1, 1000 microseconds
    setPulseWidth(pulseWidth);  // long pulseWidth = 950; // width of a pulse in microseconds
  } else {
    Timer1.disablePwm(TIMER1_PIN1);
    xxxx = 0;
  }
}

void doAfterRitardoTrigged() {
  allarm.alarmTriggered();
}

void timerDoLCDbacklight() {
  if (mostraMenu == true) {
    mostraMenu = false;
    allarm.standby();
  }
  allarm.lcd.noBacklight();
}

void inviaSMScomando(char* message_str, char type = '2') {

#ifdef DEBUG_SMS
  Serial.print("Num: ");
  //	Serial.println(number_str);
  Serial.print("Msg: ");
  Serial.println(message_str);
#endif
  //String cmd = "2|" + String(number_str) + "|" + String(message_str) + "~";
  String cmd = String(type) + "|" + String(message_str) + "~";
  allarm.sendI2CCmd(cmd, GSMI2C);
}

/********************************************************/

MandJBeep::MandJBeep(MJLcd& _lcd)
  : lcd(_lcd) {
    this->alarmeAttivo = false;
  this->statoAllarme = false;
  this->adminZone = false;
  this->ritardoAttivato = false;    
}

/**
 * funzione che stampa su LCD
 */
void MandJBeep::standby() {
  //display time and date
  lcd.clear();
  lcd.setCursor(0, 0);
  if (this->alarmeAttivo) {
    lcd.print( TXT_SYS_ACTIVE);
  } else{
    lcd.print(TXT_ENTER_PIN);
    }
  lcd.mjPrint(0,1, clock.getDate());
  lcd.mjPrint(5,3,TXT_AUTOR);
}

/*
 * funzione che formatta per stampa su LCD di data e ora
 */
// String MandJBeep::getDate() {
//   String txt = F("");
// #ifndef CLKDS3231
//   txt += printDigit(clock.now.hour()) + F(":");
//   txt += printDigit(clock.now.minute()); // + F(":");
//   //txt += printDigit(clock.now.second());
//   txt += TXT_SPAZIO;
//   txt += printDigit(clock.now.day()) + F("/");
//   txt += printDigit(clock.now.month()) + F("/");
//   txt += printDigit(clock.now.year());
// #else
//   txt += printDigit(clock.now.Hour()) + F(":");
//   txt += printDigit(clock.now.Minute()); // + F(":");
//   //txt += printDigit(clock.now.Second());
//   txt += TXT_SPAZIO;
//   txt += printDigit(clock.now.Day()) + F("/");
//   txt += printDigit(clock.now.Month()) + F("/");
//   txt += printDigit(clock.now.Year());
// #endif

// #ifdef DEBUG
// #ifdef DEBUG_PRINTDATA
//   Serial.print(F("date: "));
//   Serial.println(txt);
// #endif
// #endif
//   return txt;
// }

/*
 * check la password di admin
 */
bool MandJBeep::checkPassword2() {
  return password.evaluate();
}

/*
 * check la password di attivazione
 * 	se corretta e l'allarme non attivo ==>  fa i controlli prima dell'attivazione
 * 		altrimento lo disattiva
 */
void MandJBeep::checkPassword() {
  if (password.evaluate()) {
    if (this->alarmeAttivo == false && this->statoAllarme == false) {
      primaDiAttivare();
    } else if (this->alarmeAttivo == true || this->statoAllarme == true)
      disattiva();
  } else
    codiceErrato(0);
}

/*
 *
 */
void MandJBeep::codiceErrato(char adm = 0) {
  password.reset();
  lcd.clear();

  if (adm == 0) {
    lcd.mjPrint(3,0,TXT_INVALID_PIN);
  } else {
    password.set(settings.alarmPassword1);
    lcd.mjPrint(0,0,TXT_INVALID_ADMIN_PIN);
  }
  lcd.mjPrint(5,2,TXT_RIPROVA_PIN);
  delay(1000);
  allarm.standby();
}

/*
 *  esegue il checkSensori, se tutto ok attiva gli eventi:
 *    - ritardo attivazione
 *    - dopo ritardo attiva allarme
 */
void MandJBeep::primaDiAttivare() {
#ifdef DEBUG
  Serial.println(F("Ritardo attivazione ..........."));
#endif
  lcd.backlight();
  if (this->checkSensori()) {
    if (settings.tempoRitardo % 2 == 0)
      xxxx = 0;
    else
      xxxx = 1;
    position2 = position;
    conta = 0;
    this->ritardoAttivato = true;
    this->attiva();
    evRitardoAttivazione = this->mjTimer.every(1, doPrintRitAttivazione, settings.tempoRitardo);
    evAfterRitardoTrigger = this->mjTimer.after(settings.tempoRitardo, doAfterRitActivate);
    this->standby();
  }
}

/*
 * attiva allarme, azzera password, attiva/disattiva led, se il comando è arrivato tramite sms
 * invia sms
 */
void MandJBeep::attiva() {
  this->alarmeAttivo = true;
  this->statoAllarme = true;
  password.reset();

  digitalWrite(RED_LED, HIGH);
  digitalWrite(GREEN_LED, LOW);

  this->standby();
  if (position2 > 0) {
    char txtTemp[13] = "ATTIVO";
    inviaSMScomando(/*phone_number,*/ txtTemp);
    position2 = 0;
  }
}

/*
 * diattiva allarme, azzera password, attiva/disattiva led, disattiva TImer1PWM, disattiva sirena
 * se il comando è arrivato tramite sms invia sms
 */
void MandJBeep::disattiva() {
  this->statoAllarme = false;
  this->alarmeAttivo = false;

  //if (ritardoTriggedGiaAttivato==1)
  if (this->ritardoAttivato) {
    //ritardoTriggedGiaAttivato=0;
    this->mjTimer.stop(evRitardoAttivazione);
    this->mjTimer.stop(evAfterRitardoTrigger);
    this->ritardoAttivato = true;
  }

  password.reset();
  Timer1.disablePwm(TIMER1_PIN1);

  digitalWrite(RED_LED, LOW);
  digitalWrite(GREEN_LED, HIGH);
  digitalWrite(RELAY_SIRENA1, HIGH);

  lcd.backlight();
  lcd.clear();
  
  lcd.mjPrint(0,0,TXT_SISTEMA_DISATTIVO);

  delay(4000);
  this->standby();
  this->riAttivaSensori();

  if (position > 0) {
    char txtTemp[13] = "DISATTIVO";
    inviaSMScomando(/*phone_number,*/ txtTemp);
  }
}

/*
 * Intrusione:
 *   - attiva Timer1PWM
 *   - attiva sirena
 *   - invio sms
 *   - salva evento nella EPROM
 *   - dopo tempoSirena secondi disattiva la sirena
 */
void MandJBeep::alarmTriggered() {
  if (allarm.ritardoAttivato) {
    allarm.ritardoAttivato = false;
    // TODO stoppare fase attivazione ritardata
    this->mjTimer.stop(evRitardoAttivazione);
    this->mjTimer.stop(evAfterRitardoTrigger);
  }

  /*if (ritardoTriggedGiaAttivato==1)
	{
		ritardoTriggedGiaAttivato=0;
		this->t.stop(evRitardoAttivazione);
		this->t.stop(evAfterRitardoTrigger);
	}*/

  Timer1.initialize(period);  // initialize timer1, 1000 microseconds
  setPulseWidth(pulseWidth);  // long pulseWidth = 950; // width of a pulse in microseconds

  digitalWrite(RELAY_SIRENA1, LOW);

  password.reset();
  this->statoAllarme = true;

  lcd.clear();
  
  lcd.mjPrint(5,2,TXT_INTRUSIONE);
  lcd.mjPrint(0, 3,"");

  for (uint8_t i = 0; i < numSens; i++) {
    if (sensore[i].getStato() == sensTrigged) {
      lcd.print(sensore[i].getMessaggio());
      allarm.salvaEventoEprom(i);

      //if (started==true)
      if (settings.gsm == 1) {
        String msg = "Intrusione: " + sensore[i].getMessaggio();
        msg.toCharArray(sms_text, 160);
        //Serial.println(sms_text);
        inviaSMScomando(sms_text, '3');
      }
    }
  }
  mjTimer.after(settings.tempoSirena, doAfterTimerT);
}

void MandJBeep::alarmTriggeredRitardato(uint8_t sensId) {
  //if (allarm.ritardoAttivato=false;ritardoTriggedGiaAttivato==0) // controlla se altro evento già avviato
  if (allarm.ritardoAttivato == false)  // controlla se altro evento già avviato
  {
    if (settings.tempoRitardo % 2 == 0) xxxx = 0;
    else xxxx = 1;
    conta = 0;
    allarm.ritardoAttivato = true;
    //ritardoTriggedGiaAttivato=1;
    evRitardoAttivazione = mjTimer.every(1, doPrintRitAttivazione, settings.tempoRitardo);
    evAfterRitardoTrigger = mjTimer.after(settings.tempoRitardo, doAfterRitardoTrigged);
  }
}

void MandJBeep::inizializza() {
  //saveSettings();
  loadSettings();
  password.set(settings.alarmPassword1);

  keypad.begin(makeKeymap(keys));
  keypad.addEventListener(keypadEvent);  //add an event listener for this keypad

  clock.inizializza();
  inizializzaLed();
  inizializzaSensori();
}

void MandJBeep::saveSettings(void) {
  byte* p = (byte*)&settings;
  for (int i = 12; i < sizeof(AlarmSettings); i++)
    EEPROM.write(i, p[i]);
}

void MandJBeep::loadSettings(void) {
  byte* p = (byte*)&settings;
  for (int i = 12; i < sizeof(AlarmSettings); i++)
    p[i] = EEPROM.read(i);
}

boolean MandJBeep::checkSensori() {
  for (int i = 0; i < numSens; i++)
    if (sensore[i].getStato() == sensMalfunzionamento)
      sensore[i].setStato(sensAttivo);

  for (int i = 0; i < numSens; i++) {
    if (sensore[i].getStato() != sensDisabilitato
        and sensore[i].getStato() != sensTempDisabilitato) {
      if (sensore[i].getTipo() == tpReed) {
        if (PCF_24.read(sensore[i].getPin())
            == sensore[i].getLogica()) {
          sensore[i].setStato(sensMalfunzionamento);

          lcd.clear();
          lcd.setCursor(0, 2);
          lcd.print(F("Err: "));
          lcd.print(sensore[i].getMessaggio());

          if (settings.gsm) {
            if (position > 0) {
              String msg = "Err: " + sensore[i].getMessaggio();
              msg.toCharArray(sms_text, 160);
              inviaSMScomando(/*phone_number,*/ sms_text);
            }
          }

          password.reset();
          passwd_pos = 9;
          return false;
        }
      }
    }
  }
  password.reset();
  passwd_pos = 9;
  standby();
  return true;
}

void MandJBeep::disattivaSensori() {
  for (int i = 0; i < numSens; i++) {
    if (sensore[i].getStato() == sensMalfunzionamento) {
      sensore[i].setStato(sensTempDisabilitato);
      //PORTB |= _BV(PB0);
      digitalWrite(GIALLO_LED, HIGH);

      if (settings.gsm) {
        if (position > 0) {
          String msg = "Sens.Disattivo: " + sensore[i].getMessaggio();
          msg.toCharArray(sms_text, 160);
          inviaSMScomando(sms_text);
        }
      }
    }
  }
  password.reset();
  passwd_pos = 9;
  standby();
}

void MandJBeep::riAttivaSensori() {
  for (int i = 0; i < numSens; i++) {
    if (sensore[i].getStato() != sensDisabilitato) {
      sensore[i].setStato(sensAttivo);
      sensore[i].setConta(0);
      //PORTB &= ~(_BV(PB0));
      digitalWrite(GIALLO_LED, LOW);
    }
  }
  password.reset();
  passwd_pos = 9;
  standby();
}

void MandJBeep::salvaEventoEprom(int num) {
  EEPROM.write(6, EEPROM.read(0));
  EEPROM.write(7, EEPROM.read(1));
  EEPROM.write(8, EEPROM.read(2));
  EEPROM.write(9, EEPROM.read(3));
  EEPROM.write(10, EEPROM.read(4));
  EEPROM.write(11, EEPROM.read(5));

  EEPROM.write(0, num);

#ifndef CLKDS3231
  EEPROM.write(1, clock.now.day());
  EEPROM.write(2, clock.now.month());
  EEPROM.write(3, clock.now.year() - 2000);
  EEPROM.write(4, clock.now.hour());
  EEPROM.write(5, clock.now.minute());
#else
  EEPROM.write(1, clock.now.Day());
  EEPROM.write(2, clock.now.Month());
  EEPROM.write(3, clock.now.Year() - 2000);
  EEPROM.write(4, clock.now.Hour());
  EEPROM.write(5, clock.now.Minute());
#endif
}

String MandJBeep::leggiEventoEprom(byte a) {  // S:num sensore|gg/mm/yy|hh:mm
  if (a == 0)
    return (String)sensore[EEPROM.read(0)].getMessaggio() + F("|")
           + printDigit(EEPROM.read(1)) + printDigit(EEPROM.read(2))
           + printDigit(EEPROM.read(3)) + F("|")
           + printDigit(EEPROM.read(4)) + printDigit(EEPROM.read(5));
  else
    return (String)sensore[EEPROM.read(6)].getMessaggio() + F("|")
           + printDigit(EEPROM.read(7)) + printDigit(EEPROM.read(8))
           + printDigit(EEPROM.read(9)) + F("|")
           + printDigit(EEPROM.read(10)) + printDigit(EEPROM.read(11));
}

void MandJBeep::inizializzaLed() {
  pinMode(GREEN_LED, OUTPUT);
  pinMode(RED_LED, OUTPUT);
  pinMode(RELAY_SIRENA1, OUTPUT);
  pinMode(GIALLO_LED, OUTPUT);
  pinMode(TIMER1_PIN1, OUTPUT);
  pinMode(TIMER1_PIN2, OUTPUT);

  digitalWrite(RELAY_SIRENA1, HIGH);
  digitalWrite(RED_LED, LOW);
  digitalWrite(GIALLO_LED, LOW);
  digitalWrite(GREEN_LED, HIGH);
}

void MandJBeep::inizializzaSensori() {
  for (int i = 0; i < numSens; i++)
    sensore[i].setStato(
      (bitRead(settings.sens, i) == 0 ? sensDisabilitato : sensAttivo));
}

void MandJBeep::checkAttivita() {
  if (this->alarmeAttivo) {
    for (uint8_t i = 0; i < numSens; i++) {
#ifdef DEBUG_SENS
      Serial.print("sens ");
      Serial.print(sensore[i].getMessaggio());
      Serial.print(" - stato");
      Serial.println(sensore[i].getStato());
#endif

      if ((sensore[i].getStato() != sensDisabilitato) and (sensore[i].getStato() != sensTempDisabilitato)) {


        if (sensore[i].getRitardato() == true and allarm.ritardoAttivato == true) {
          //caso: in fase di attivazione
          /*} else
				/*if (sensore[i].getRitardato()==true and allarm.ritardoAttivato==false) {
					// attivare procedura allarm trigged ritardata
					sensore[i].setStato(sensTrigged);
					this->alarmTriggeredRitardato(i);*/
        } else if (sensore[i].getZona() == settings.zona or settings.zona == znTotale) {
          if (PCF_24.read(sensore[i].getPin()) == sensore[i].getLogica() and sensore[i].getStato() != sensTrigged) {
            sensore[i].setStato(sensTrigged);
            if (sensore[i].getRitardato())
              this->alarmTriggeredRitardato(i);  // TODO: forse parametro inutile !!!!
            else this->alarmTriggered();

            if (sensore[i].getTipo() == tpReed) {
              if (sensore[i].getConta() >= settings.maxReed_Conta) {
                sensore[i].setStato(sensTempDisabilitato);
              }
              sensore[i].setConta((sensore[i].getConta() + 1));
            }
          }
#ifdef DEBUG_PIR
          if (sensore[i].getTipo() == tpPIR) {
            Serial.print("PIR: ");
            Serial.println(PCF_24.read(sensore[i].getPin()));
          }
#endif
        }
      }
    }
  } else {
    /*for (uint8_t i = 0; i < numSens; i++) {
			if (sensore[i].getTipo() == tpTamper) {
#ifdef DEBUG_SENS
				Serial.print("sens ");
				Serial.print(sensore[i].getMessaggio());
				Serial.print(" - stato");
				Serial.println(sensore[i].getStato());
#endif
				if ((sensore[i].getStato() != sensDisabilitato)
						and (sensore[i].getStato() != sensTempDisabilitato)) {
					if (PCF_24.read(sensore[i].getPin())
							== sensore[i].getLogica()
							and sensore[i].getStato() != sensTrigged) {
						//sensore[i].setStato(sensTrigged);

						digitalWrite(GIALLO_LED, HIGH);
					}/*else{
					 sensore[i].setStato(sensAttivo);
					 digitalWrite(GIALLO_LED, LOW);

					 }*/
    /*}

			} else if (sensore[i].getTipo() == tpSirena) {

			}

		}*/
  }
}
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

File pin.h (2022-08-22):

/**
 * Project Title: M&J Beep
 * Author: M&J
 * Started Date: 09/02/2016
 * Version: 1.0
 * Licence: GPL ver 3
 **/
#ifndef _Pin_H_
#define _Pin_H_

#include "Arduino.h"

#include "Sensore.h"

#define BAUD_RATE  9600  //115200

// software reset
#define Reset_AVR() wdt_enable(WDTO_30MS); while(1) {}

//#define DEBUG
#ifdef DEBUG
//	#define DEBUG_KEY
//	#define DEBUG_SETTINGS
//	#define DEBUG_SENS
//	#define DEBUG_SENS2
//	#define DEBUG_PIR
//	#define DEBUG_SECTIMER
//	#define DEBUG_PRINTDATA
//	#define DEBUG_SMS
#endif

#define ROWS  4  // Four rows
#define COLS  4  // Four columns

const char keys[ROWS][COLS] = { // Define the Keymap
	{ '1', '2', '3', 'A' },
	{ '4', '5', '6', 'B' },
	{ '7', '8', '9', 'C' },
	{ '*', '0', '#', 'D' } };

#define I2CADDR 0x21 //keypad
static byte rowPins[ROWS] = { 3, 2, 1, 0 }; //connect to the row pinouts of the keypad
static byte colPins[COLS] = { 7, 6, 5, 4 }; //connect to the column pinouts of the keypad

#define TIMER1_PIN1 13 //13   //buzzer pin
#define TIMER1_PIN2 12   //buzzer pin

#define GREEN_LED  2
#define RED_LED    3
#define GIALLO_LED  1
//#define RELAY_SIRENA1 11
#define RELAY_SIRENA1 14
//#define RELAY_SIRENA2 7

//Indirizzo I2C Slave GSM
#define GSMI2C 0x08

/************* LCD *************/
#define I2C_ADDR    0x20 // LCD: Define I2C Address for controller
#define BACKLIGHT_PIN  7
#define En_pin  4
#define Rw_pin  5
#define Rs_pin  6
#define D4_pin  0
#define D5_pin  1
#define D6_pin  2
#define D7_pin  3
//LiquidCrystal_I2C  lcd(I2C_ADDR,En_pin,Rw_pin,Rs_pin,D4_pin,D5_pin,D6_pin,D7_pin, BACKLIGHT_PIN, NEGATIVE);
/*===============================*/

static uint8_t passwd_pos = 9;  // the postition of the password input

// id timer event
static int8_t timerLCDbacklight = 0;
static int8_t timerPrintData = 0;
static int8_t timerReadGSMSlave = 0;
static int8_t evRitardoAttivazione=0;
static int8_t evAfterRitardoTrigger=0;

/**********************************************************
 **    Definizione di stringhe
 ***********************************************************/
#define TXT_AUTOR              F("Beep by M&J")
#define TXT_SYS_ACTIVE         F("Attivo: ")
#define TXT_ENTER_PIN          F("Codice: ")
#define TXT_INVALID_PIN        F("Codice errato!")
#define TXT_INVALID_ADMIN_PIN  F("Codice Admin errato!")
#define TXT_RIPROVA_PIN        F("Riprova")
#define TXT_SISTEMA_DISATTIVO  F("Sistema Disattivato!")
#define TXT_INTRUSIONE   	   F("Intrusione")
#define TXT_SPAZIO			   F(" ")
#define TXT_INIZIALIZZA_GSM	   "Inizializza GSM.."

//#define TXT_MENU               "Menu"
#define TXT_SICUREZZA			"Sicurezza"
#define TXT_ATTIVA				"Attiva"
#define TXT_PERIMETRALE			"Perimetrale"
#define TXT_INTERNO				"Interno"
#define TXT_TOTALE				"Totale"
#define TXT_DISATTIVA_SENSORI	"Dis.Temp.Sensori"
#define TXT_IMPOSTAZIONE       	"Impostazioni"
#define TXT_SAVE_TO_EPROM     	"Salva EPROM"
#define TXT_LOAD_TO_EPROM      	"Carica EEPROM"
#define TXT_TEMPO_SIRENA       	"Tempo Sirena"
#define TXT_TEMPO_RITARDO      	"Tempo Ritardo"
#define TXT_CONTA_REED			"ContaReed"
#define TXT_LCDBACK_LIGHT_TIME 	"Retroillum"
#define TXT_ADMIN_PASSWORD     	"Admin Password "
#define TXT_PASSWORD1          	"Password1 "
#define TXT_PASSWORD2          	"Password2 "
#define TXT_CONFERMA			"#conferma"
#define TXT_REPORT  			"Report"
#define TXT_SENSORI				"Sensori"
#define TXT_ATTIVA_GSM		    "Attiva GSM"
#define TXT_DISATTIVA_GSM		"Disattiva GSM"
#define TXT_GSM                 "GSM"
#define TXT_NUMERI_GSM          "Numeri"
#define TXT_NUMERI1_GSM          "Numero1"
#define TXT_NUMERI2_GSM          "Numero2"
#define TXT_NUMERI3_GSM          "Numero3"
#define TXT_NUMERI4_GSM          "Numero4"
#define TXT_NUMERI5_GSM          "Numero5"
#define TXT_SYNC_GSM             "Sync Imp GSM"
#define TXT_STATE_GSM            "Stato GSM"
#define TXT_GSM_READY			 "GSM READY"
#define TXT_GSM_NOT_READY		 "GSM Not Ready"
#define TXT_RIAVVIA_GSM			 "Riavvia"
#define TXT_TEMPERATURA			"Temperatura: "
#define TXT_DATA_ORA        "Data/Ora"
#define TXT_DATA        "Data"
#define TXT_ORA        "Ora"
//#define TXT_ATTDIS_GSM       (settings.gsm==0?TXT_ATTIVA_GSM:TXT_DISATTIVA_GSM)
/**********************************************************/
static boolean mostraMenu = false;
/**********************************************************/

/************ Sensori ************/
//numero sensori
#define numSens 8
// pin del PCF8574 connessi al sensore
#define I2C_REED1_PIN 0
#define I2C_REED2_PIN 1
#define I2C_REED3_PIN 2
#define I2C_REED4_PIN 3
#define I2C_PIR0_PIN 4
#define I2C_PIR1_PIN  5
#define I2C_GUASTISIRENA_PIN  6
#define I2C_TAMPER_PIN  7
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

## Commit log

2016-03-07 primo invio
    [doc.ods]
2016-03-07 File compatibilità con IDE Arduino
2016-03-08 cambio modalità di impostazione dei pin, usando accesso registro diretto
2016-03-11 Schemi elettronici
    [Sensori_I2C_pcf8574.fzz]
2016-05-21 corretto check sensori: setto stato sensAttivo ai sensori con stato SensMalfunzionamento prima di verificarne lo stato
2016-06-01 app per gestione remoto (ricordarsi di impostare lingua "Italiano" in appInventor)
2016-12-10 mod gestione tempo ritardo sensori
2016-12-10 Modifiche per la gestione del ritardo qunado un sensore rileva un infrazione
2022-08-19 - definizione funzione printerttings
2022-08-21 - modifiche schema fritz
    [baseBoard1284.fzz, baseBoard1284_new.fzz]
2022-08-22 - spostati definizione del settings e dei sensore dal file MandJBepp.h al file pin.h
